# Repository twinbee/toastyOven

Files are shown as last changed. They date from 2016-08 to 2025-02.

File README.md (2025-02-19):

# ToastyOven#
 is a repo for a very cheap Arduino-controller PCB flow / reflow oven for the after-population soldering of existing Printed circuit boards (PCBs).  Contributors are github user @twinbee @LKAPBx

The approach taken is low budget / minimum viable product (MVP). The oven features one LED for status, and one button for control. 

Many others have produced fancy ovens with OLED / TFT diplays and many buttons. This is not that.. This is minimal and cheap enough to get a good result; No more, no less.

Licensed under the Mozilla Public License 2.0 (MPL2). See LICENSE for more details. Copy right Matthew Bennett, Luke Andrews 2016.

## Bill of materials ##
1. A cheap toaster 
oven ($24 new or $15 thrifted)
2. Solid state relays capable of a few amps (two, about $9 each)
3. Arduino. I used an UNO I had lying around. ($25)
4. USB cable for programming or changing profile ($5)
5. Type K thermocouples (one or two, $11 each)
6. A way to get the thermocouple data to the arduino. We used a 1-wire board from 
7. Push button ($1)

Sum total is about $125

## Hookup diagram ##
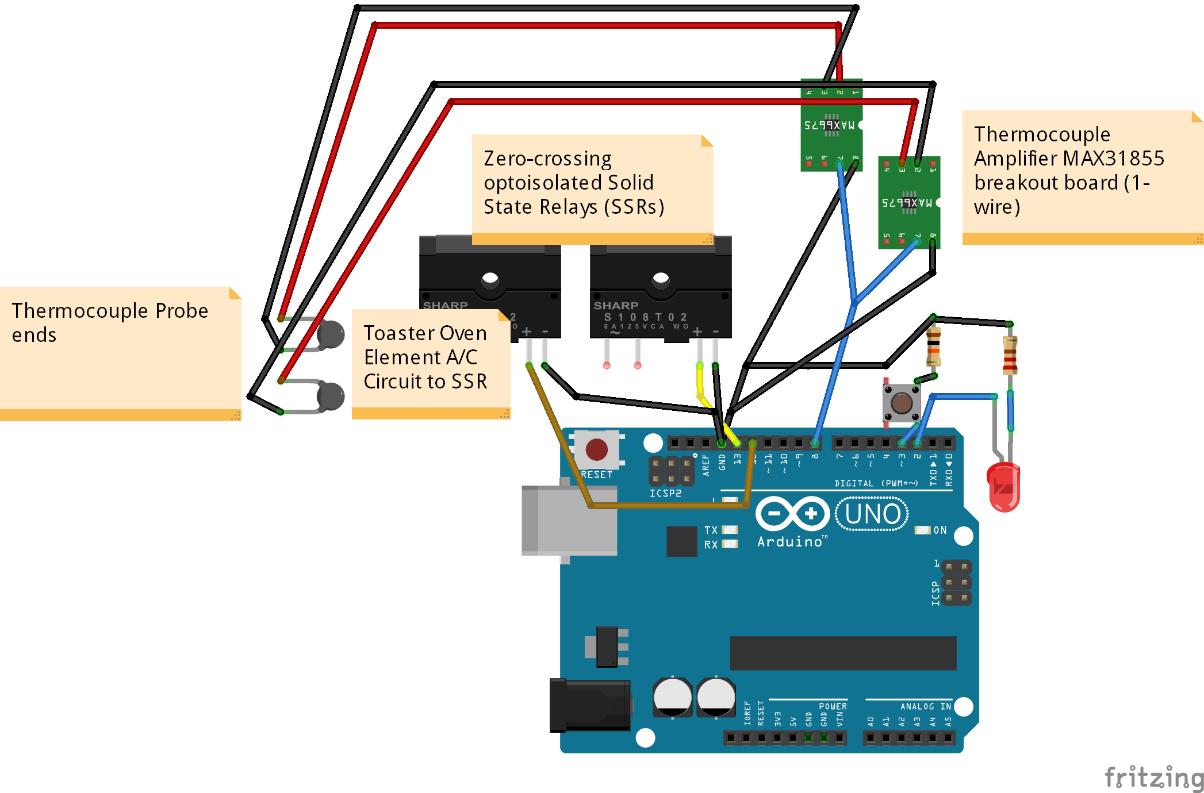
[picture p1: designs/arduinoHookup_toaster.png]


## Schematic (DC side) ##
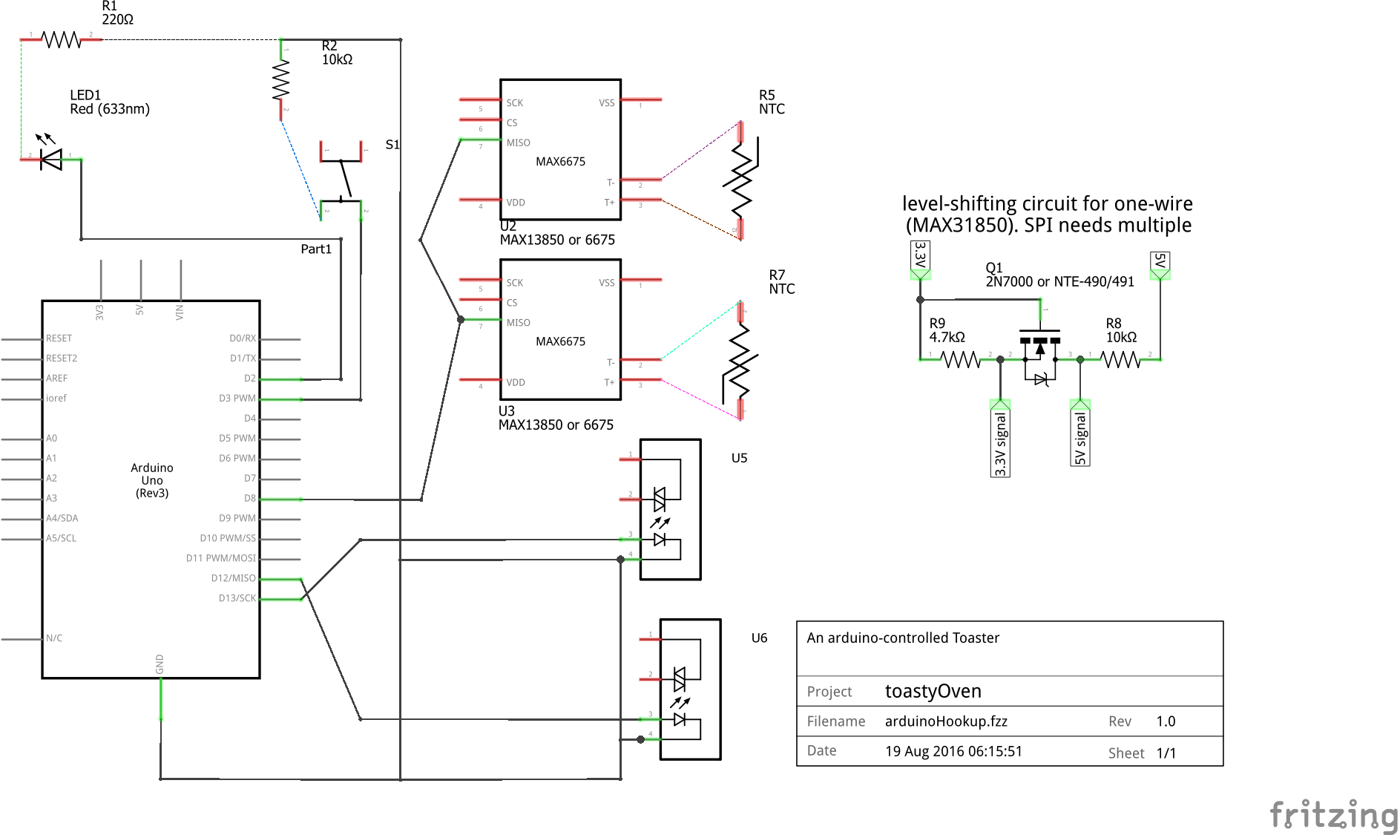
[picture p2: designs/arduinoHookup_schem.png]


## Building your toastyOven ##

Wire the elements to the AC side of an SSR. Be sure to include the door switch and the fire prevention over-temperature sensor that came with your oven as series elements in the circuit, if applicable. Wire a pin on the arduino to the DC side of the SSR. Do not solder any connections which will live inside the toaster if you can avoid it, as the side cavity of a toaster oven may get hot enough to melt solder. Instead, crimp and use heat shrink. Use either quick disconnect terminals or butt-splice connectors. 

On the DC side, connect the arduino pin 13 to the SSR as illustrated in the fritzing diagram or image found in the designs folder. Connect the button to arduino pin 2 via a 10KOhm pull-down resistor. Connect the LED to arduino pin 3 via a 220-Ohm pull-down resistor (or similar value based on the LED color and desired brightness). Connect the thermocouple amplifier to arduino pin 8 via the instructions from the thermocouple amplifier manufacturer (e.g. adaFruit). Connect a USB cable to computer if serial output desired, otherwise connect a USB cable to USB port supply. Connect a piezo buzzer to Arduino pin 5 if sound is desired. Put everything together physically and move on to the profile step.   

## github Repo Structure ##
**duino** Contains the Arduino-based controller code. **designs** contains physical designs including some 3d-printable parts with sketchup models and wiring schematics. **processing**Contains code to take serial input from the arduino and plot it as a graph of temperature over time, for further tweaking

## Toaster Usage ##
The toaster may have a number of baking profiles up to the total number allowed by Arduino program memory space constraints. To select a profile, press the button the number of times desired until the LED is blinking the correct number for that profile. If you go past the last profile the selection will loop back to the first one. 

When you are satisfied, hold the button down for three seconds without releasing it, and the profile will begin. Once the profile has completed, the toastyOven is reset and awaiting another profile / run.

## Arduino Firmware: Creating a custom profile ##
Each profile should be written as a function with a function pointer stored in the global array profiles near the top of the code. Examples are provided.

    void profile1()
    {
    //times are in seconds
    //temps are in degrees Centigrade
    
      Serial.println("profile1: MEMS mics");
    // Preheat 160C
    //Dwell 120s
    //Ramp Up 1C/s for 98s
    //Dwell  30s
    //Ramp Down 1C/s for 98s
    //Ramp Off
    cookTemps[0] = 160;
    cookTimes[0] = 120;
    
    cookTemps[1] = 220;
    cookTimes[1] = 30;
    
    cookTemps[2] = 160;
    cookTimes[2] = 60;
    
    cookTemps[3] = 40;
    cookTimes[3] = 30;
    
    }  

After writing your profile, be sure to add it to the functor list and adjust numProfiles.

    const int NUM_PROFILES = 3;
    void (* profiles  [NUM_PROFILES]) () = { profile1, profile2, profile3 };

If you wish to increase the number of stages in a profile, it is here. Just be sure to zero out the profiles you aren't using.

    const int NUM_STAGES = 4;
    int cookTemps[NUM_STAGES] = {0,0,0,0};
    int cookTimes[NUM_STAGES] = {0,0,0,0};

You may also want to configure the hysteresis buffer with a different temperature range.
   
    // a buffer used for hysteresis / dampening.
    //  within epsilon degrees is "good enough" 
    //  to count time toward our goal time for 
    //  that stage
    // Use half the value that you actually want
    // so if you want the range to be 10 degrees,
    //  e.g. 500C +/-5C, use 5.0C
    int tempEpsilon = 5; 
    
That's it! Enjoy a tasty circuit board at home.

## Toaster AC-side Schematic ##

For our project, everything we needed was in a cabinet to the right side of the toaster. We removed all mechanical timers / knob controls and we left the emergency over-temp breaker device and the door switch in series with the power coming in.

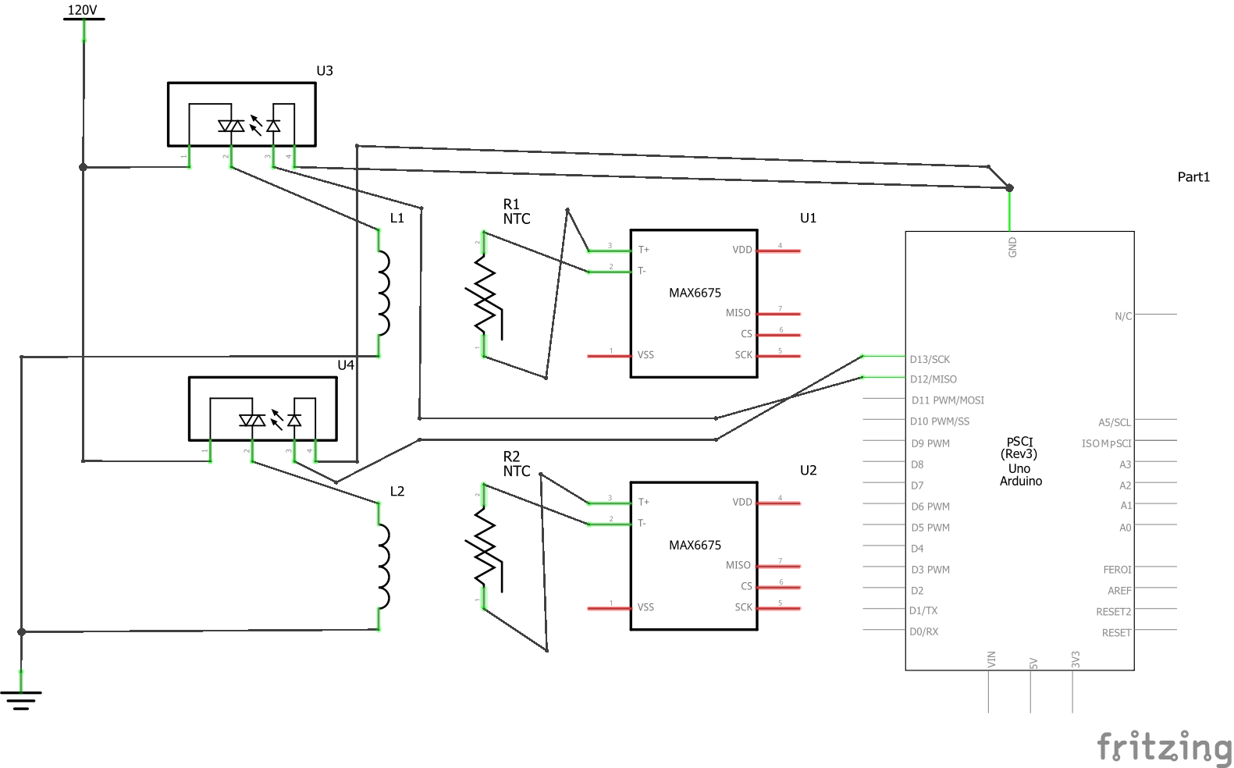
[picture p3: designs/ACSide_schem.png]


Figure: AC side wiring

## Bench Testing Firmware ##

If you don't have the thermocouple circuit, you can use a simple 10K-Ohm potentiometer on one of the Analog input pins. If you don't have the toaster oven element circuit / SSR, you may use an LED to show when the oven element(s) are on.

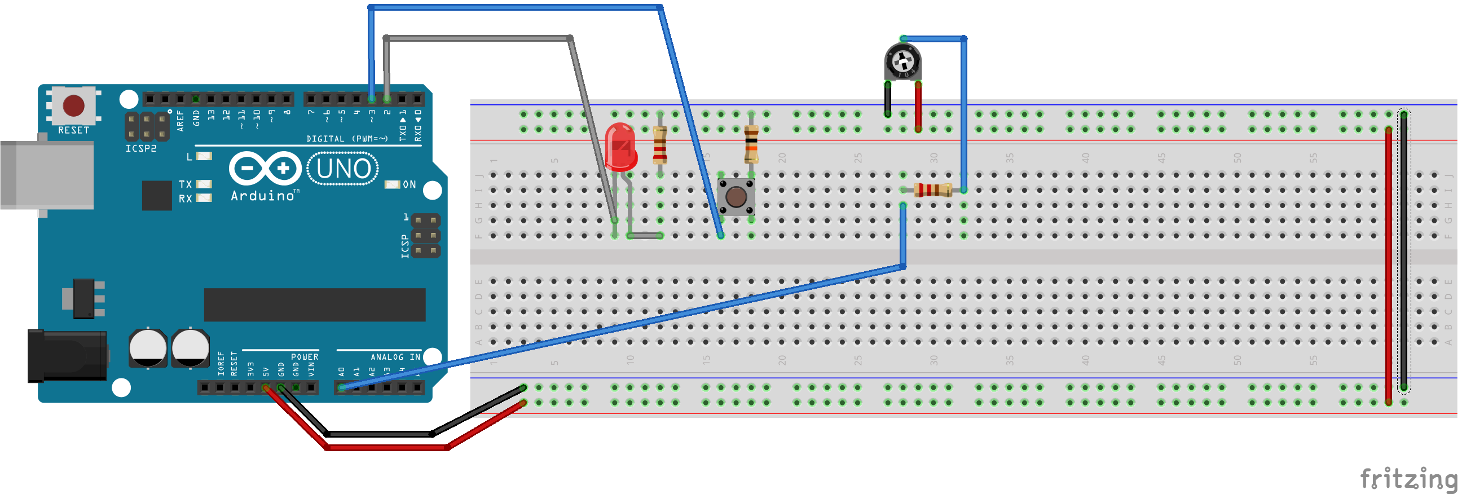
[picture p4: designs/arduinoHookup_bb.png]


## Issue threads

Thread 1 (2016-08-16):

Top heater element is only element in use.

ILMPBx, 2016-08-16:
Suggest utilizing bottom element also. It may prove useful to also provide a duty cycle mechanism such that one or the other element may be switched on/off at a chosen duty cycle rate while the other element remains on continuously. This mechanism could help prevent uneven top-to-bottom heating?

Closed 2016-09-16.

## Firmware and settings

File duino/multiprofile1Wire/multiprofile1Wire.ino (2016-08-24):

/**
ToastyOven arduino code by Matthew A Bennett, 2016
Licensed under the Mozilla Public License v 2.0

  A very minimal toaster oven reflow oven controller using 
   arduino, SSRs, thermocouples/amps, and 
   
   To use, fill out a 4-stage profile functor and add to the array "profiles"
    Use profile1() as an example
   When you turn on the toaster, a short button press changes profiles
   The LED will blink a number of times to indicate the profile setting
   When you have the one you want, hold the button for three seconds.
   
   Serial port will spit out diagnostic data you can use for profiling
    in a CSV format of: time,temp,TopOn,BottomOn
*/

///////////////////////////////////////////////////////////////////////
// API part (e.g. make your own profile)
///////////////////////////////////////////////////////////////////////

#include <OneWire.h>
#include <DallasTemperature.h>

// PID controller constants
const float k_p = 1.0f;
const float k_i = 100.0f;
const float k_d = 100.0f;

// Setup a oneWire instance to communicate with any OneWire devices (not just Maxim/Dallas temperature ICs)

const int BUTTONPIN = 4;
const int LEDPIN = 13;
const int BOTTOMELEMENT = 12;
const int TOPELEMENT = 11;

const int ONE_WIRE_BUS = 2;
OneWire oneWire(ONE_WIRE_BUS);

// Pass our oneWire reference to Dallas Temperature. 
DallasTemperature sensors(&oneWire);

// arrays to hold device address
DeviceAddress insideThermometer;


const int NUM_PROFILES = 3;
void (* profiles  [NUM_PROFILES]) () = { profile1, profile2, profile3 };

const int NUM_STAGES = 4;
int setPoints[NUM_STAGES] = {0,0,0,0};
int setPointDurations[NUM_STAGES] = {0,0,0,0};

// a buffer used for hysteresis / dampening.
//  within epsilon degrees is "good enough" 
//  to count time toward our goal time for 
//  that stage
// Use half the value that you actually want
// so if you want the range to be 10 degrees,
//  e.g. 500C +/-5C, use 5.0C
int tempEpsilon = 5; 

void profile1()
{
//times are in seconds
//temps are in degrees Centigrade

  Serial.println("profile1: MEMS mics");
// Preheat 160C
//Dwell 120s
//Ramp Up 1C/s for 98s
//Dwell  30s
//Ramp Down 1C/s for 98s
//Ramp Off
setPoints[0] = 160;
setPointDurations[0] = 120;

setPoints[1] = 220;
setPointDurations[1] = 30;

setPoints[2] = 160;
setPointDurations[2] = 60;

setPoints[3] = 40;
setPointDurations[3] = 30;

}

void profile2()
{
   Serial.println("profile2: nothing");
   
setPoints[0] = 160;
setPointDurations[0] = 120;

setPoints[1] = 220;
setPointDurations[1] = 30;

setPoints[2] = 160;
setPointDurations[2] = 10;

setPoints[3] = 40;
setPointDurations[3] = 30;
}

void profile3()
{
   Serial.println("profile3: nothing");
      
setPoints[0] = 160;
setPointDurations[0] = 120;

setPoints[1] = 220;
setPointDurations[1] = 30;

setPoints[2] = 160;
setPointDurations[2] = 10;

setPoints[3] = 40;
setPointDurations[3] = 30;
}


/////////////////////////////////////////////////////////////////////////
// Base code part (no need to edit but go to town if you want to!)
/////////////////////////////////////////////////////////////////////////
float error = 0.0f;
float integral = 0.0f;
float derivative = 0.0f;

float pidOut = 0.0f;

float lastSample = 0.0f;
unsigned long lastSampleTime = millis();
unsigned long sampleTime = millis();

// in duty cycles, 010101 means on, off, on, off, on, off when going right to left
const byte dutyCycle0 = 0b00000000;
const byte dutyCycle25 = 0b10001000;
const byte dutyCycle50 = 0b10101010;
const byte  dutyCycle625 = 0b10101110;
const byte  dutyCycle75 = 0b11101110;
const byte  dutyCycle875 = 0b11111110;
const byte dutyCycle100 = 0b11111111;

byte duty = dutyCycle0;

byte dutyCycleCounter = 0;

int profileChosen = -1;
bool profileAcknowledged = false;

bool lastButton = false;
bool buttonState = false;
unsigned long timeButtonPressed = 0;

//status of the environment
float currentTemp1 = 0;
float currentTemp2 = 0;
bool element1 = false;
bool element2 = false;

unsigned long timeTempReached = 0;
unsigned long timeAtGoal = 0;

int profileStage = 0;

//pot used for simulating temperature during development
int sensorPin = A0; 

// the setup function runs once when you press reset or power the board
void setup() {
  Serial.begin(9600);

  // locate devices on the bus
  Serial.print("Locating devices...");
  sensors.begin();
  Serial.print("Found ");
  Serial.print(sensors.getDeviceCount(), DEC);
  Serial.println(" devices.");

  // report parasite power requirements
  Serial.print("Parasite power is: "); 
  if (sensors.isParasitePowerMode()) Serial.println("ON");
  else Serial.println("OFF");
  
  // assign address manually.  the addresses below will beed to be changed
  // to valid device addresses on your bus.  device address can be retrieved
  // by using either oneWire.search(deviceAddress) or individually via
  // sensors.getAddress(deviceAddress, index)
  //insideThermometer = { 0x28, 0x1D, 0x39, 0x31, 0x2, 0x0, 0x0, 0xF0 };

  // Method 1:
  // search for devices on the bus and assign based on an index.  ideally,
  // you would do this to initially discover addresses on the bus and then 
  // use those addresses and manually assign them (see above) once you know 
  // the devices on your bus (and assuming they don't change).
  if (!sensors.getAddress(insideThermometer, 0)) Serial.println("Unable to find address for Device 0"); 
  
  // method 2: search()
  // search() looks for the next device. Returns 1 if a new address has been
  // returned. A zero might mean that the bus is shorted, there are no devices, 
  // or you have already retrieved all of them.  It might be a good idea to 
  // check the CRC to make sure you didn't get garbage.  The order is 
  // deterministic. You will always get the same devices in the same order
  //
  // Must be called before search()
  //oneWire.reset_search();
  // assigns the first address found to insideThermometer
  //if (!oneWire.search(insideThermometer)) Serial.println("Unable to find address for insideThermometer");

  // show the addresses we found on the bus
  Serial.print("Device 0 Address: ");
  printAddress(insideThermometer);
  Serial.println();

  // set the resolution to 9 bit (Each Dallas/Maxim device is capable of several different resolutions)
  sensors.setResolution(insideThermometer, 9);
 
  Serial.print("Device 0 Resolution: ");
  Serial.print(sensors.getResolution(insideThermometer), DEC); 
  Serial.println();
  
  getTemp ();
  Serial.print("Temp: ");
  Serial.print(currentTemp1, DEC); 
  if (currentTemp1 > 200 || currentTemp1 < 0) 
  {
    Serial.println(" FATAL: Temp ");
    while (true) blinkOutError();
  }
  
  
  pinMode(BOTTOMELEMENT, OUTPUT);
  pinMode(TOPELEMENT, OUTPUT);

  pinMode(LEDPIN, OUTPUT);

  pinMode(BUTTONPIN, INPUT);
  
  digitalWrite(LEDPIN, HIGH);
  
  blinkOutAck();

}

// the loop function runs over and over again forever
void loop() {
if (!profileAcknowledged)
{
  collectProfileSetting();
}
 else   
    {
      checkButtonForResetEvent();
      controlElements();
      getTemp ();    // to be replaced with getting the temp from the thermocouple or RTD
      calculatePid();
      outputData();
      reactToTemp();
      advancePhase();
    }
    delay(500);
} //end main event loop

void calculatePid()
{
 error = setPoints[profileStage] - currentTemp1;
 derivative = (lastSample - currentTemp1)/(lastSampleTime - sampleTime + 1);
 integral += error/(lastSampleTime - sampleTime);
 
 pidOut = k_p*error + k_i*integral + k_d*derivative;
}

void controlElements()
{
 dutyCycleCounter = (dutyCycleCounter + 1)%8;
 
 //counterth  bit of dutyCycle
 element1 = (duty & ( 1 << dutyCycleCounter%8 )) >> dutyCycleCounter%8;
 element2 = (duty & ( 1 << (dutyCycleCounter+1)%8 )) >> (dutyCycleCounter+1)%8;
 
 if (element1)
 {
  digitalWrite(TOPELEMENT, true);
 }
 else //if (!element1)
 {
  digitalWrite(TOPELEMENT, false);
 }
 
 if (element2)
 {
  digitalWrite(BOTTOMELEMENT, true);
 }
 else //if (!element2)
 {
  digitalWrite(BOTTOMELEMENT, false);
 }
}

void getTemp ()
{
  sensors.requestTemperatures();
  
  lastSampleTime = sampleTime;
  sampleTime = millis();
  
  lastSample = currentTemp1;

  currentTemp1 = sensors.getTempC(insideThermometer);
  //currentTemp1 = analogRead(sensorPin);  
}

void outputData()
{
  Serial.print(millis());
  Serial.print(",");
  Serial.print(currentTemp1);
  Serial.print(",On?");
  Serial.print(element1);
  Serial.print(":");
  Serial.print(element2);
  Serial.print(",");
  Serial.print(setPoints[profileStage]);
  Serial.print(",");
  Serial.print(setPointDurations[profileStage]);  
  Serial.print(",");
  Serial.print(timeAtGoal);  
  Serial.print(",");
  Serial.print(profileChosen);
  Serial.print("[");
  Serial.print(profileStage);
  Serial.print("],");  
  Serial.print(duty, 2); // print in base 2
  Serial.print(",");  
  Serial.print(error,4);
  Serial.print(",");  
  Serial.print(integral,8);
  Serial.print(",");  
  Serial.print(derivative,8);
  Serial.print(",");  
  Serial.print(pidOut,8);
  Serial.print(",");  
    
    //overshoot condition!
  if ( currentTemp1 > (setPoints[profileStage] + tempEpsilon) )
  {
   Serial.print(",!OVER!");
  }

  Serial.println ();
}


void collectProfileSetting()
{
  buttonState = digitalRead(BUTTONPIN);

  while (!profileAcknowledged)
  {
  if (buttonState == HIGH) 
  {
    if (lastButton != buttonState) 
    {
      timeButtonPressed = millis();
    }
  } 
  else //  if (buttonState == LOW) 
  {
    if (lastButton != buttonState && millis() - timeButtonPressed > 30) 
    {
      //Serial.print("B-off after ");
      //Serial.println(millis() - timeButtonPressed);
      
      if (millis() - timeButtonPressed < 1000)
      {
       profileChosen++;
       profileChosen %= NUM_PROFILES;
       Serial.print("Selected profile: ");
       Serial.println(profileChosen+1);
       blinkOutProfileChosen();
      }
      else 
      {
       profileAcknowledged = true;
       blinkOutAck();
       blinkOutProfileChosen();
       blinkOutAck();
       //do the settings for the given profile
       profiles[profileChosen](); 
       break;
      }      
    }
 }
 lastButton = buttonState;
 buttonState= digitalRead(BUTTONPIN);
} //end while

      timeButtonPressed = 0;
}

void  checkButtonForResetEvent()
{
  lastButton = buttonState;
  buttonState = digitalRead(BUTTONPIN);

   if (buttonState == HIGH) 
   {
        Serial.println("!RESET!");
        resetSoft();
   }      
}

void blinkOutProfileChosen()
{
     digitalWrite(LEDPIN, LOW);
     delay (200);
     
     for (int i = 1; i <= profileChosen+1; i++)
     {
     digitalWrite(LEDPIN, HIGH);
     delay (200);
     
     digitalWrite(LEDPIN, LOW);
     delay (100);
     }
     
     digitalWrite(LEDPIN, LOW);
     delay (100);
     
     digitalWrite(LEDPIN, LOW);
}

void blinkOutAck()
{
     for (int i = 1; i <= 4; i++)
     {
     digitalWrite(LEDPIN, HIGH);
     delay (50);
     
     digitalWrite(LEDPIN, LOW);
     delay (50);
     }
}

void blinkOutError()
{
     for (int i = 1; i <= 4; i++)
     {
     digitalWrite(LEDPIN, HIGH);
     delay (500);
     
     digitalWrite(LEDPIN, LOW);
     delay (500);
     }
}

void reactToTemp ()
{
 if ( currentTemp1 > setPoints[profileStage] - tempEpsilon )
 {
  //first time that the temp was reached
  if (
      timeTempReached < 1 ) 
  {
    timeTempReached = millis();
  }
  else
  {
    timeAtGoal = (millis() - timeTempReached);
  }

}

 //Part deux: take care of the duty cycle
 // TODO: add reaction as PID control

  // Case 1: so many overshoot!
  //if (currentTemp1 > setPoints[profileStage] + tempEpsilon ) 
  if (pidOut < -2.0*tempEpsilon)
  {
   duty = dutyCycle0;
  }
  //Case 2: such overshoot!
  //else if (currentTemp1 > setPoints[profileStage] )
  else if (pidOut < -tempEpsilon)
  {  
   duty = dutyCycle50;
  }
  //else if (currentTemp1 > setPoints[profileStage] - tempEpsilon )
  else if (pidOut < 0.0 )
  {
    duty = dutyCycle625;
  }
  //else if (currentTemp1 < setPoints[profileStage] - 2*tempEpsilon )
  else if (pidOut < tempEpsilon )
  {
    duty = dutyCycle75;
  }
  else if (pidOut < 2.0*tempEpsilon )
  {
    duty = dutyCycle875;
  }
  else if (pidOut < 3.0*tempEpsilon )
  {
    duty = dutyCycle100;
  }
  else //a long, long way to go and many ob-stackles in your path
    //  --the oracle from o brother, where art thou?
  {
    duty = dutyCycle100;
  }
  
}

void resetSoft()
{
  digitalWrite(TOPELEMENT, 0);
  digitalWrite(BOTTOMELEMENT, 0);
  element1 = false;
  element2 = false;
  duty = 
   profileStage = 0;
   profileChosen = -1;
   profileAcknowledged = false;
}

void advancePhase ()
{
 if (profileStage >= NUM_STAGES) 
 { 
   Serial.println("Resetting");
   resetSoft();
 }

 else if (timeAtGoal > 1000UL*setPointDurations[profileStage])
 {
  profileStage += 1;
  timeAtGoal = 0UL;
  timeTempReached = 0UL;
 }
} 
 
 // function to print a device address
void printAddress(DeviceAddress deviceAddress)
{
  for (uint8_t i = 0; i < 8; i++)
  {
    if (deviceAddress[i] < 16) Serial.print("0");
    Serial.print(deviceAddress[i], HEX);
  }
}

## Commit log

2016-08-15 Added multi-profile support using button andstatus LED
2016-08-15 Fix late night bug
    [multiprofile.ino]
2016-08-15 Arduino IDE wants a subfolder with the same name as the sketch
2016-08-16 add debounce for button and hysteresis buffer for temperature
2016-08-16 add emergency soft reset (push the button while running profile)
    [multiprofile.ino]
2016-08-16 add emergency soft reset (push the button while running profile) and instructions to readme
2016-08-16 Revert "add emergency soft reset (push the button while running profile) and instructions to readme"
    This reverts commit b7e141264b780cbd99dae4902ad3bac25f8e7e48.
2016-08-16 Revert "Revert "add emergency soft reset (push the button while running profile) and instructions to readme""
    This reverts commit 8210dda54c2a727f0d123ede26c42933ce25f629.
2016-08-16 Fix units typo in comments
    [multiprofile.ino]
2016-08-17 Add fritzing / design documents
    [arduinoHookup.fzz]
2016-08-17 Add diagrams to readme
    [ACSideSchematic.fzz]
2016-08-19 update schematics with SSR
    [arduinoHookup.fzz]
2016-08-21 update schematics
    [arduinoHookup.fzz]
2016-08-22 After wiring. Seperate out analog from one-wire
2016-08-22 Remove emergency reset call for testing
    [multiprofile1Wire.ino]
2016-08-22 Fix SW bug causing overshoot
    [multiprofile1Wire.ino]
2016-08-24 use PID in check
2016-08-24 tune PID and remove test code (analog pot)
2016-08-24 get credit for stage if within epsilon
